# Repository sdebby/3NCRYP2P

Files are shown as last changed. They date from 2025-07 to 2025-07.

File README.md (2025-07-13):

# LoRaOmniScreenKB

Project start date: Jan. 2024

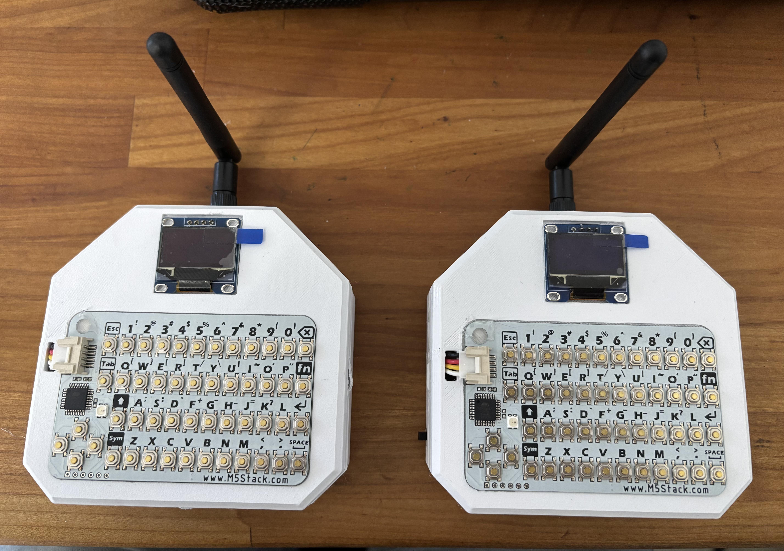
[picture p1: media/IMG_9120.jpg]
Overview picture


## Overview

3NCRYPT2P (Encrypt P2P) project, designed to enable secure, wireless communication between two devices or more, on long ranges, using LoRa (Long Range communication) technology (on 433 Mhz transmission), without cellular networks. The system features an OLED screen (SSD1306) and a CardKB keyboard for user interaction. Both sender and receiver run the same firmware, supporting encrypted messaging, key exchange, and visual feedback.

## MRD (Marketing Requirement)

- Provide a simple, secure, and portable LoRa-based communication terminal.
- Support up to 6 lines of message history on a compact OLED display.
- Enable secure key exchange and encrypted messaging between devices.
- Allow easy user input via a compact keyboard.
- Feedback for system status and errors using debug.
- New transmission protocol for secure communication between devices.

## Skill Set

- Embedded C++ programming (Arduino/ESP32).
- LoRa wireless communication.
- Cryptography (AES, SHA224, CTR mode).
- 3D design.
- 3D printing.

## Setup (Software Setup)

1. **Hardware Requirements:**
   - ESP32-S3 or ESP32-C6 development board
   - LoRa module (433MHz)
   - SSD1306 OLED display (I2C)
   - CardKB keyboard (I2C)
   - Required wiring and power supply

2. **Software Requirements:**
   - Arduino IDE (latest version recommended)
   - ESP32 board support installed via Board Manager
   - Required libraries:
     - Adafruit_SSD1306
     - LoRa
     - AES, CTR, SHA224 (Crypto libraries)
     - Preferences (for ESP32 NVS)
     - base64

3. **Flashing the Firmware:**
   - Clone or download this repository.
   - Open `LoRaOmniScreenKB.ino` in Arduino IDE.
   - Select the correct board and port.
   - Install all required libraries via Library Manager.
   - Compile and upload the firmware to your ESP32 board.

## BOM (Bill Of Materials):

**For R&D:**

1. ESP32 C6 dev kit
2. [LoRa RA02](https://docs.ai-thinker.com/_media/lora/docs/c048ps01a1_ra-02_product_specification_v1.1.pdf) (433 MHz module)
3. [SSD1306 OLED](https://www.adafruit.com/product/938) (64x64 pixels, I2C)
4. [CardKB keyboard](https://docs.m5stack.com/en/unit/cardkb_1.1) (I2C)
5. Breadboard and jumper wires
   
**For production:**
1. ESP32 C6 dev kit
2. [LoRa RA02](https://docs.ai-thinker.com/_media/lora/docs/c048ps01a1_ra-02_product_specification_v1.1.pdf) (433 MHz module)
3. [SSD1306 OLED](https://www.adafruit.com/product/938) (64x64 pixels, I2C)
4. [CardKB keyboard](https://docs.m5stack.com/en/unit/cardkb_1.1) (I2C)
5. [Charger panel](https://www.aliexpress.com/item/1005005037876729.html?spm=a2g0o.order_list.order_list_main.386.6b881802CcDzO8)
6. 433 MHz antenna.
7. LiPo battery 850 mAh.
8. On/Off switch.
9. Custom PCB manufacturing.
10. 3D printing for enclosure.

## Software:

1. Arduino IDE for coding and uploading to ESP32 C6 board.
2. KiCad for PCB design.
3. Fusion360 for 3D enclosure design

## TSD (Technical Specification)

- Microcontroller: ESP32-S3 or ESP32-C6
- Display: SSD1306 OLED, 64x64 pixel
- Keyboard: CardKB
- LoRa: 433MHz, configurable sync word, bandwidth, spreading factor, and power
- Encryption: AES-128 in CTR mode, SHA224 for message hashing, base64 for hash encoding
- Key Exchange: Random key and IV generation, secure transmission
- Error Handling: Device lockout after repeated errors, visual and serial feedback
- Message Handling: Up to 6 lines of message history, scrolling, and input editing

## Scheme

1. **Startup:**
- Display logo and initialize peripherals.
- Check for device lock status.

1. **Key Exchange:**
- On first message, generate and exchange encryption keys and IVs.
- encrypt key using predefined embedded key.
- from now on all messages will be encrypted with the exchanged key, and random IV.

1. **Message Transmission:**
- User inputs message via CardKB or serial (debug mode).
- Message is hashed, encrypted, and transmitted over LoRa.
- Await acknowledgment from receiver.

1. **Message Reception:**
- Decrypt incoming messages using the exchanged key and received IV.
- Verify hash for integrity.
- Display message on OLED and send acknowledgment.

1. **Error Handling:**
- If hash check fails or no acknowledgment is received, display message on OLED, handle retries, and lock device after 10 repeated errors.

### Transmission Protocol
| Field | Description |
|---|---|
| Setup bit | indicator for message type |
| Payload | Encrypted message content |

**Case Setup Bit = 0:**
Packet format:
A | B | C | D | E 

A - Setup bit (Byte) (0).

B - Key length (byte).

C - Key (byte array).

D - IV length(byte).

E - IV (byte array)

**Case Setup Bit = 1:**
Packet format:

A | B | C | D | E | F | G

A - Setup bit (byte) (1).

B - IV length (byte).

C - IV (byte array).

D - payload length (byte).

E - payload (byte array).

F - Hash length (byte).

G - Hash - Base64 (SHA224(payload)) (byte array)

**Case Setup Bit = 2:**
Packet format:

A | B

A - Setup bit (byte) (2).

B - payload reply (int).

### Reply payload
* 200 if payload hash OK

* 502 if payload hash not OK

### Transmission scheme example

Case setup bit = 0

  generate random key
  generate random iv
  Send message by this order:
    Setup
      - 0 for key replace.
    key size
    key
    iv size
    iv

Case setup bit = 1
  User payload input
  Encrypt payload using key and IV
  Create SHA224 hash of payload
  Convert hash to Base64
  Send message by this order:
    Setup
      - 1 for normal text payload
    payload size 
    payload 
    iv size 
    iv 
    text hash size 
    text hash

  Getting random IV

Listen to receiver hash result.
print result status (OK/wrong hash)

if result is wrong hash -> procedure to setup bit 0 case, count number of wrong hashes, if more than 10 times, lock device.

## Receiving payload
Receive message by this order:
  Setup
    - 0 for encrypted new key
    - 1 for normal text payload
    - 2 payload reply
  payload size 
  payload 
  iv size 
  iv 
  text hash size 
  text hash

Decrypt message using key and IV from message
Create SHA224 hash of message
Compare received hash and created hash.

reply on compare results.

Case setup bit = 2
  Sending payload reply (OK/ERROR)

## Security features

1. **Encryption:** All messages are encrypted using AES-128 in CTR mode.
2. **Key Exchange:** Secure key exchange is performed during the initial connection.
3. **Integrity Check:** Message integrity is verified using SHA224 hashes.
4. **Brute Force Protection:** After 10 consecutive errors, the device locks out to prevent further communication until reset.

## Schematics

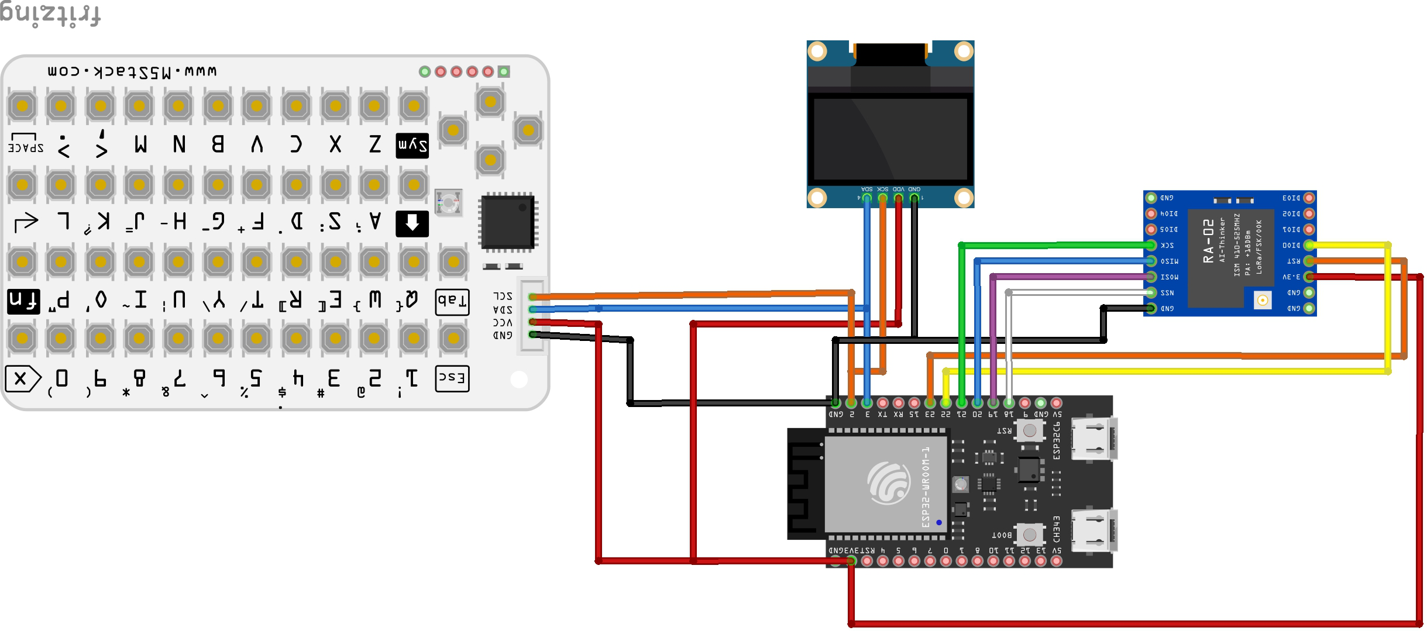
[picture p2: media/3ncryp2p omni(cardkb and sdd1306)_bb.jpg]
Scheme


## PCB

* PCB design using KiCad
* 2 layers PCB
* PCB manufacturing using PCBWay
  
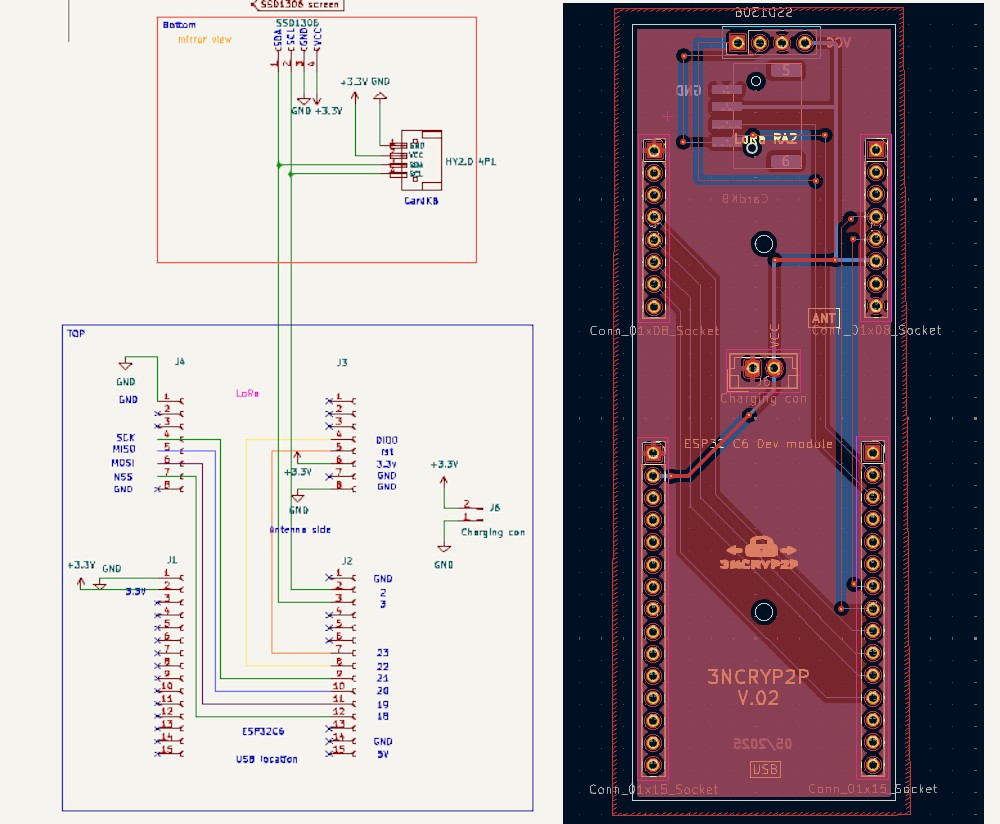
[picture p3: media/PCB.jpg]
PCB


## Hardware assembly:

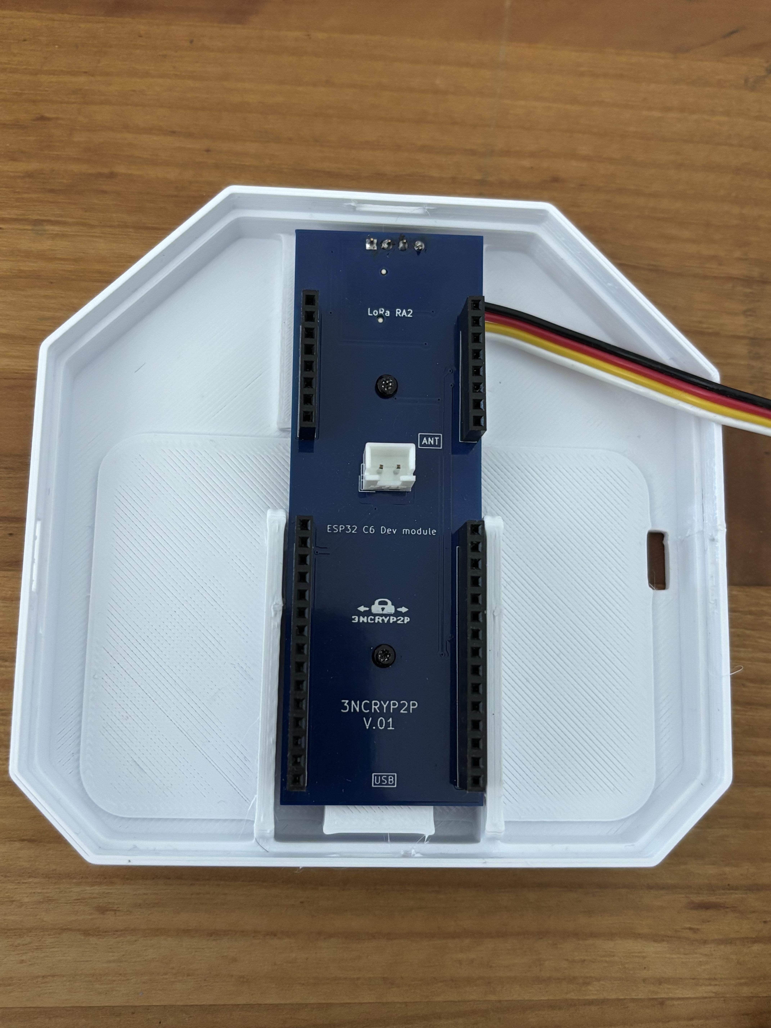
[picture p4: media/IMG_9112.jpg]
PCB Assembly on 3D print top enclosure


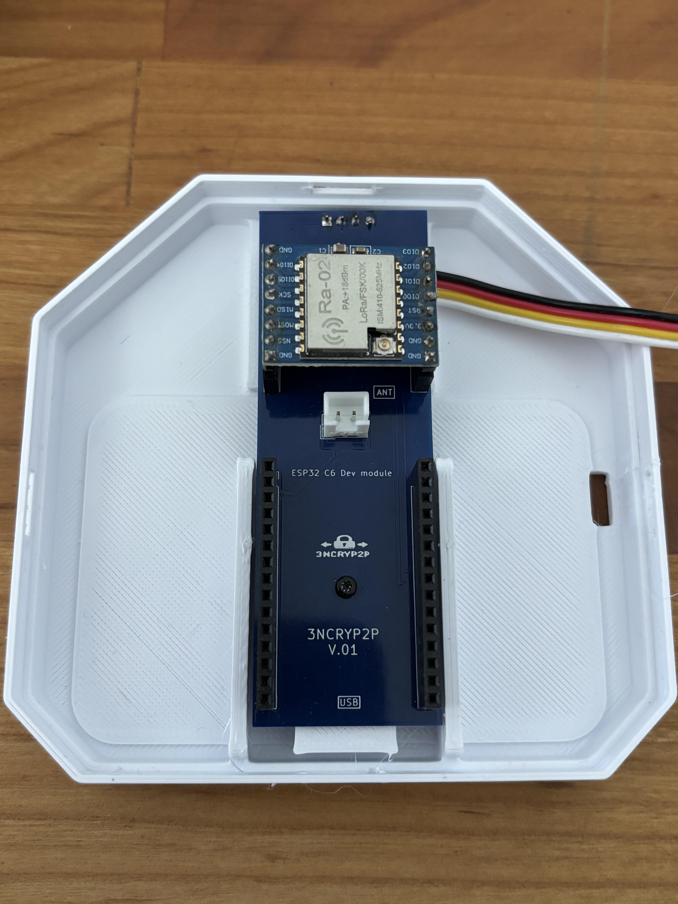
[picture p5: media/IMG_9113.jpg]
Adding RA02 LoRa module


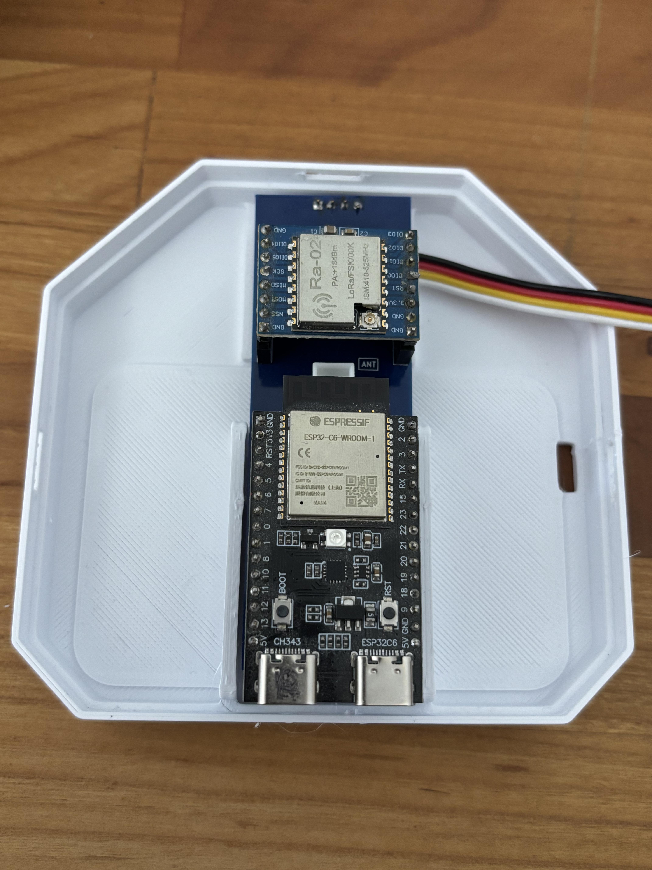
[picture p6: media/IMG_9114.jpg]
Adding ESP32C6


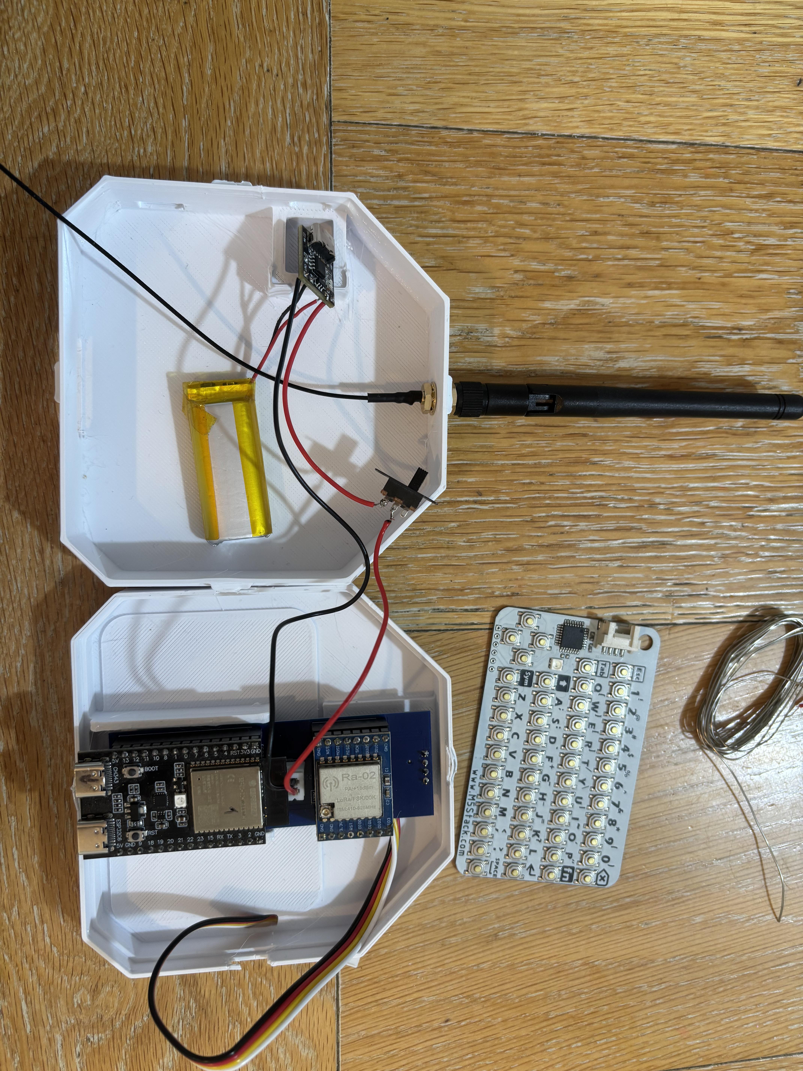
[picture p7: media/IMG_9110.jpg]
Adding USB charging, Antenna and battery


### 3D enclosure design

* Using Fusion360
* 3D print using Ender 5 plus with PLA filament.
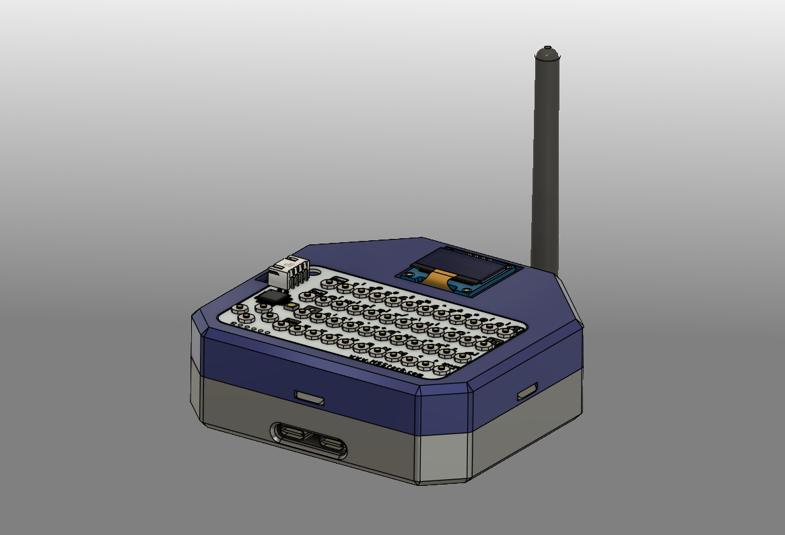
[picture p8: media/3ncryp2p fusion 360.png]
Fusion360 Design


## Range test
Sender

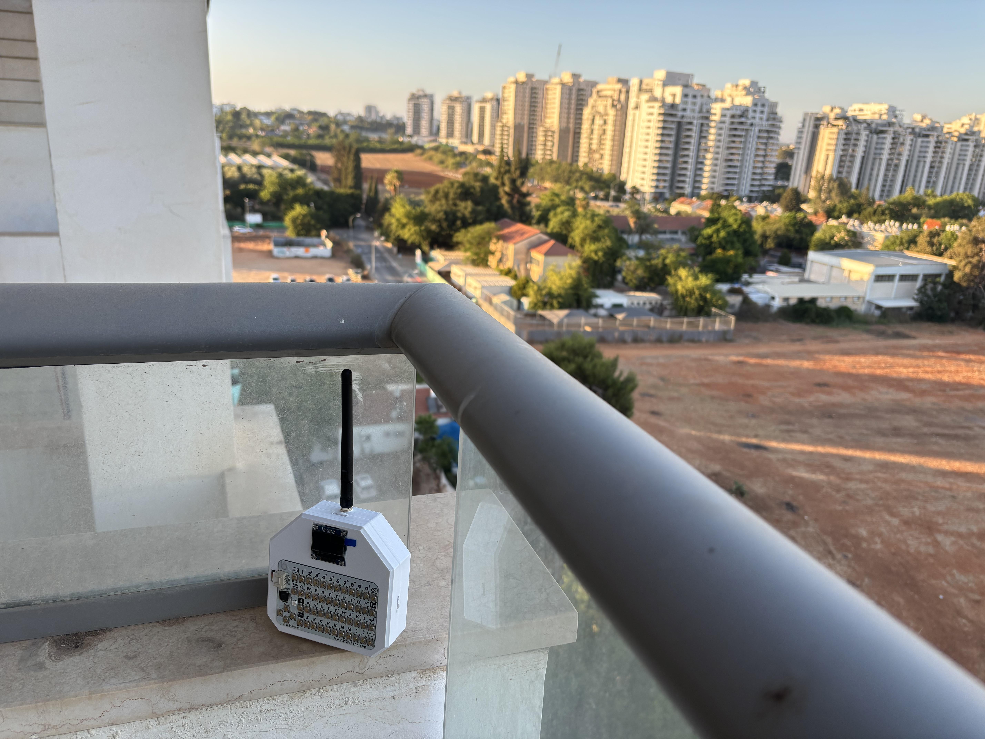
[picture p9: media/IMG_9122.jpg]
Sender


Receiver

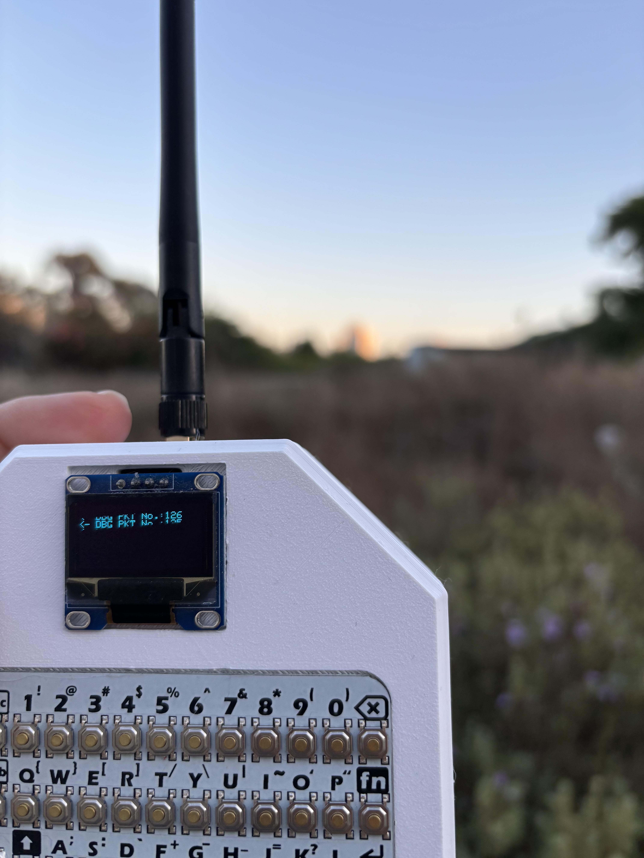
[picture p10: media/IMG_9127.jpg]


**Line of sight distance** 1.5 km

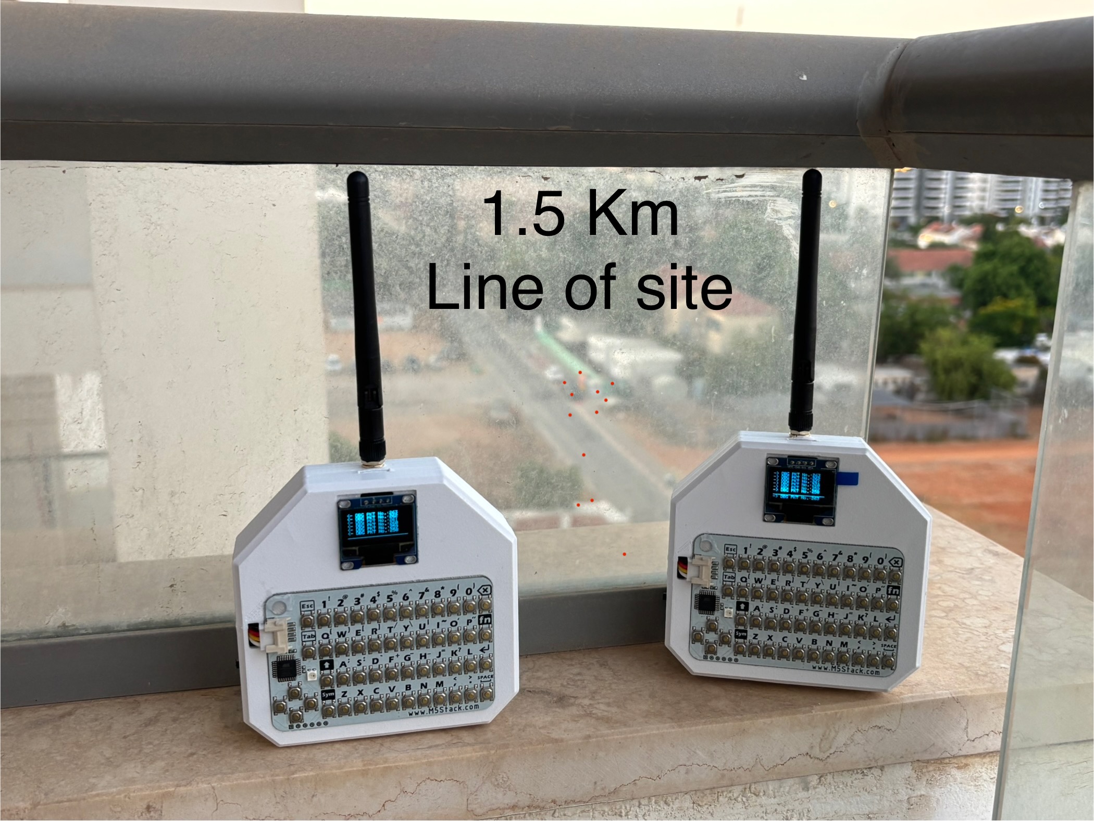
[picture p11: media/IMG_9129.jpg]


**Non-line of sight distance** 400 - 500 m

## Video

(https://youtu.be/woUXP3gD4LY)

## TODO
- [ ] Implement a short range, predefined key exchange mechanism, using Thread protocol or ESP-NOW.
- [ ] Implement a more robust error handling mechanism.
- [ ] Add support for multiple devices in a network.
- [ ] Replace screen with a larger one for better user experience.
- [ ] Implement a more user-friendly interface for message input and display - replace screen with 128x64 OLED display or E-INK display.
- [ ] Implement a secure bootloader to prevent unauthorized firmware updates. 
- [ ] Implement user message history storage and retrieval.

## Achilles heel
The Achilles' heel of the project is the hardcoded key embedded in the code. This key is used to encrypt the initial key exchange, which is crucial for secure communication. If an attacker gains access to the source code, they can extract this key and compromise the security of the entire system. 
To mitigate this risk, it is essential to implement a secure key exchange mechanism that does not rely on a hardcoded key. This could involve using public key cryptography or a secure key exchange protocol like Diffie-Hellman.

A predefined key exchange mechanism, such as using Thread protocol or ESP-NOW, could be implemented to securely exchange keys between devices without relying on a hardcoded key. This would enhance the security of the system and protect against potential attacks.

Another approach can be sending only half of the key over the air and displaying the other half on the screen, allowing the user to manually input it into the other device. This would require user interaction but would eliminate the need for a hardcoded key in the code.

Then the new, predefined key will be stored in the device's non-volatile storage (NVS) for future use, ensuring that the key is not hardcoded in the firmware.

## Feedback

If you have any feedback, please reach out to us at mailto:shmulik.debby@gmail.com

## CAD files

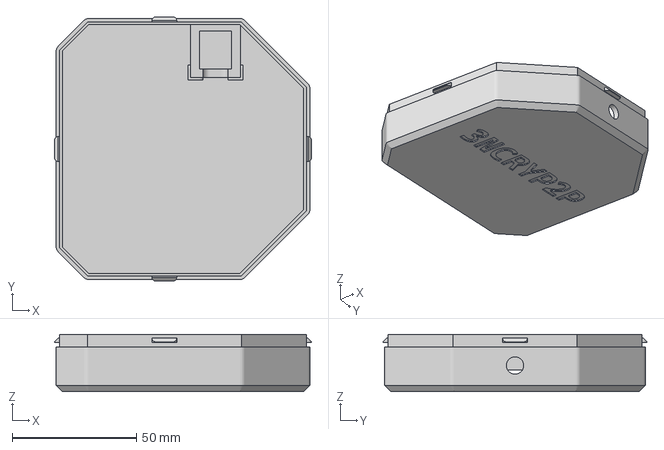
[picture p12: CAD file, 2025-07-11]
3D/3ncryp2p Enclosure BOTTOM.3mf
103.4 x 106.3 x 23.0 mm

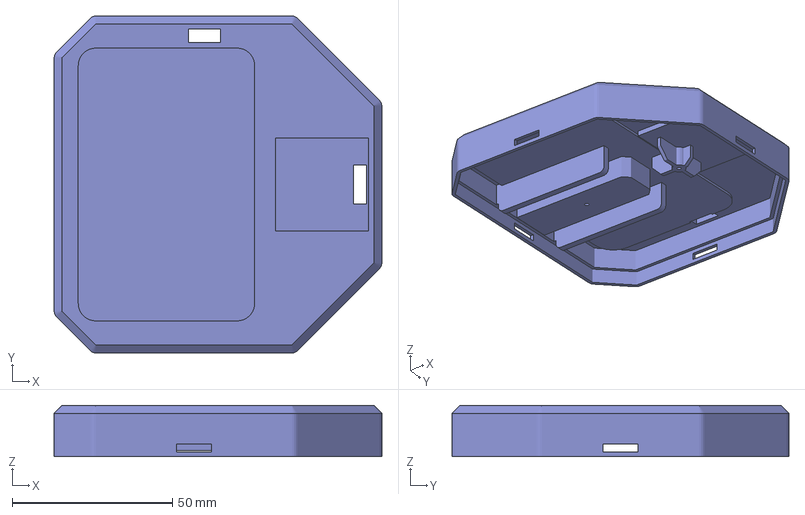
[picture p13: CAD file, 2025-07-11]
3D/3ncryp2p Enclosure TOP.3mf
102.1 x 105.0 x 16.0 mm

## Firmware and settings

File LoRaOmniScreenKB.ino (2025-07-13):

/*
11.04.2025
3NCRYPT2P project
__ Omni Screen and keyboard program __

This code will be implemented in both devices (Sender and Receiver)
the communication will be thru screen(SSD1306) and keyboard (CardKB).
** Change the AIM flag to generate automated interval messages
** Chenge to core debug level (in arduino IDE menu - Tools) to communicate using console and see system messages
*/  

#include <SPI.h>
#include <LoRa.h>
#include <AES.h>
#include "base64.hpp"
#include <base64.h>
#include <CTR.h>
#include <SHA224.h>
#include <Preferences.h>
#include "esp32-hal-log.h"

// Define screen and keyboard
#include <Wire.h>
#include <Adafruit_SSD1306.h>

#define CARDKB_ADDR 0x5F 
#define SCRN_ADDR 0x3C 

// Define screen width and height
#define SCREEN_WIDTH 128
#define SCREEN_HEIGHT 64
#define MAX_LINES 6  // Maximum number of lines that can fit on screen
#define LINE_HEIGHT 8  // Height of each line in pixels

Adafruit_SSD1306 display(SCREEN_WIDTH, SCREEN_HEIGHT, &Wire, -1);
int TextSize = 1;
String lines[MAX_LINES];  // Array to store lines
int currentLine = 0;      // Current line position

#if CONFIG_IDF_TARGET_ESP32S3  // Define LoRa-ESP32 pin out for ESP32 - S3
  #define BoadMSG  "[*] ESP32-S3 board found"
  #include <WiFi.h>
  #define ss 10
  #define rst 6
  #define dio0 5

#elif CONFIG_IDF_TARGET_ESP32C6  // Define LoRa-ESP32 pin out for ESP32 - C6
  #define BoadMSG  "[*] ESP32-C6 board found"
  #include <WiFi.h>
  #define ss 18
  #define rst 23
  #define dio0 22
  #define WireSDA 3
  #define WireSCL 2

  #else
  #error "[X] This code is for ESP32 S3 and ESP32 C6 only."
#endif

bool Consl = false; // Console mode
bool TransmissionACK = true; // Transmission acknowledge by 2nd device flag
unsigned long TransmissionMillis = 0;
const long TransmissionRcvACKInterval = 3.5 * 1000; // waiting time for Tramsnission acknowledge (milliseconds)

  // Define Encryption key
byte keyOriginal[16] = {0x5E, 0xC3, 0x7A, 0x1F, 0xB8, 0x9D, 0x42, 0x86, 0xE4, 0x3B, 0x60, 0xF5, 0x2C, 0xAB, 0x91, 0x08};
byte key[16] ;
byte iv[16] ;
CTR<AES128> ctr;

  // Debug - send messages in intervals
bool AIM = true; // AIM = Automated Interval Messages
  int counter = 0;
  unsigned long previousMillis = 0; 
  const long interval = 10 * 1000;  // intervals to send messages in ms


String RecievedMSG_Pack = "";
int RTN_OK = 200;
int RTN_NG = 502;

bool FirstMsg = true; // Check if this is the first message
int ErrCount = 0;
int ErrAllowed = 10;
Preferences preferences;
String PayloadInput = "";
String ReSendPayloadInput = "";

void setup() {
  Serial.begin(115200);
  while (!Serial);
  Serial.println("**-- LoRa OMNI SC-KB --**");
  // Get compiled debug level
  #ifdef CORE_DEBUG_LEVEL
    Serial.print("[*] CORE_DEBUG_LEVEL Value: ");
    Serial.println(CORE_DEBUG_LEVEL);  // Try printing its value
    #if CORE_DEBUG_LEVEL == 4// if compiled debug level = DEBUG
       Consl = true; 
    #endif
  #else
    Serial.println("[*] CORE_DEBUG_LEVEL is NOT defined.");
  #endif

  // I2C pins
  Wire.begin(WireSDA, WireSCL);
  // Initialize the display
  if (!display.begin(SSD1306_SWITCHCAPVCC, SCRN_ADDR)) {
    Serial.println(F("[X] SSD1306 allocation failed"));
    for (;;);
  }
  // initize display SSD1306
  LogDisp(); // Display logo on screen
  intDisp();
  intPref();
  if (preferences.getBool("DeviceLOCK",false)){ //TODO - set red light
    LockLoop();
  }
  Serial.println(BoadMSG);
	// Initialize LoRa 
  LoRa.setPins(ss, rst, dio0);
  if (!LoRa.begin(433E6)) {
    log_d("[X] Starting LoRa failed!");
    delay(100);
    while (1);
  }
  SetLoRaParam();// LoRa parameters
}

void loop() {
  unsigned long currentMillis = millis();
  onReceive(LoRa.parsePacket());
  delay(50);
  if (Consl && Serial.available()) { // Get text from serial if using debug 
    PayloadInput = Serial.readStringUntil('\n');
    SndCmd(PayloadInput);
  } else { // Get text from CardKB
    Wire.requestFrom(CARDKB_ADDR, 1);  
    while (Wire.available())  {
      char c = Wire.read();  // Store the received data.  
      PayloadInput += String(c) ;
      if (c != 0) {
        if (c == 13){  // Enter
          PayloadInput.remove (PayloadInput.length() - 1); // remove last charecter
          SndCmd(PayloadInput);
          String TmpPayloadInput = PayloadInput;
          ReSendPayloadInput = PayloadInput; // for resending payload if needed
          PayloadInput = "-> " + TmpPayloadInput;
          scrollLines();
          PayloadInput = "";
          redrawDisplay();
        }
        else if (c == 8) {  // Backspace
          int cursorX = display.getCursorX() - 6 * TextSize;
          int cursorY = display.getCursorY();
          if (cursorX < 0) cursorX = 0 ;
          display.setCursor(cursorX, cursorY);
          display.fillRect(cursorX,cursorY,cursorX + 6 * TextSize , cursorY + LINE_HEIGHT * TextSize,BLACK);
          display.display();
          if (PayloadInput.length() > 0) {
            PayloadInput.remove (PayloadInput.length() - 2); // remove last charecter
          }
          c = 0;
        } else {
        display.print(c);
        }
        display.display();
      }
    }
  }
  if (AIM){ // Generate message and send
    if (currentMillis - previousMillis >= interval) {
      previousMillis = currentMillis;
      Serial.print("[*] Sending DEBUG packet: ");
      Serial.println(counter);
      String Ttext = "DBG PKT No.:" + String(counter);
      PayloadInput = "-> " + Ttext;
      scrollLines();
      redrawDisplay();
      SndCmd(Ttext);
      counter ++;
      }
  }
  // Check if received acknowledge
  if ( currentMillis >= TransmissionMillis && currentMillis - TransmissionMillis >= TransmissionRcvACKInterval && !TransmissionACK) {
    // Message acknowledge did not receaved after TransmissionACKInterval time
    Serial.print("[X] Error sending message - no ACK");
    TransmissionACK = true;
    PayloadInput = "-X Err sending msg";
    scrollLines();
    PayloadInput = "";
    redrawDisplay();
  }

}

/* --------------------------------------- */

  // Shift all lines down by one
void scrollLines() {
  for (int i = MAX_LINES - 1; i > 0; i--) {
    lines[i] = lines[i - 1];
  }
  // Add new line at the top
  lines[0] = PayloadInput;
}

  // draw display again 
void redrawDisplay() {
  display.clearDisplay();
  for (int i = 0; i < MAX_LINES; i++) {
    display.setCursor(0, i * LINE_HEIGHT);
    display.print(lines[i]);
  }
  
  // Draw input line and separator
  display.setCursor(0, SCREEN_HEIGHT - LINE_HEIGHT);
  display.print(PayloadInput);
  int BottomLineY = SCREEN_HEIGHT - LINE_HEIGHT - 2;
  display.drawFastHLine(0, BottomLineY, SCREEN_WIDTH, WHITE);
  display.display();
}

  //initialize preferences
void intPref(){
  preferences.begin("3NCRYPT2P", false); // The second parameter is false for read/write access. Use true for read-only.
  if (AIM){
    preferences.clear();
  }
}

  // Send payload
void SndCmd(String Ttext){  // prepare and send message
  if (FirstMsg){
      NewKey();
      delay(1500);
      FirstMsg = false;
  }
  NewIV();  // generate random IV
    // Hashing text and converting to byte
  String TxtHash = Hash_base64(Ttext.c_str());
  byte* TxtSHA224 = stringToByteArray(TxtHash);
    // Encrypting
  byte* plaintext = stringToByteArray(Ttext);
  SetEnc(key,sizeof(key));
  byte ciphertext[Ttext.length()]; // Buffer for the ciphertext
  ctr.encrypt(ciphertext, plaintext, Ttext.length());
  log_d("[*] Before Encryption: %s",Ttext);
    // send packet
  SendMSG(1, Ttext.length() , ciphertext , sizeof(iv), iv, TxtHash.length(), TxtSHA224);
}

// Generate a new key , encrypt with predefine key and random IV and send
void NewKey(){
  log_d("[*] Creating new key --");
  for (int i =0 ; i<sizeof(keyOriginal) ; i++){
    key[i] = RandByte();
  }
  NewIV();
  SetEnc(keyOriginal,sizeof(keyOriginal));
  byte ciphertext[sizeof(key)]; // Buffer for the ciphertext
  ctr.encrypt(ciphertext, key, sizeof(key));

    // Send message with Setup 0
  SendMSG(0, sizeof(ciphertext),ciphertext, sizeof(iv), iv, 0, 0);
}

  // Set encryption parameters
void SetEnc(byte* inputkey,int KeySize){
  if (!ctr.setKey(inputkey, KeySize))
    log_d("[X] setKey failes!");
  if (!ctr.setIV(iv, sizeof(iv))) 
    log_d("[X] setIV failes!");
}

  // Setting LoRa parameters
void SetLoRaParam(){
  LoRa.setSyncWord(0xB2);  //Unique Sync Word
  LoRa.setSignalBandwidth(41.7E3); //7.8E3, 10.4E3, 15.6E3, 20.8E3, 31.25E3, 41.7E3, 62.5E3, 125E3, and 250E3.
  LoRa.setSpreadingFactor(9) ;  // Supported values are between `6` and `12`. If a spreading factor of `6` is set, implicit header mode must be used to transmit and receive packets.
  LoRa.setTxPower(17); //2-17 
  LoRa.enableCrc();  
  log_d("[V] LoRa init succeeded.");
}

  // generate new IV
void NewIV(){
  for (int i =0 ; i<sizeof(iv) ; i++){
    iv[i] = RandByte();
  }
}

  // onReceive  function
void onReceive(int packetSize){
  if (!packetSize) return; //Drop packet
      // Print packet data
      FirstMsg = false;
      Serial.print("[*] Packet size: "); //print to serial
      Serial.print(packetSize);
      String MyText = "  SNR: ";
      MyText += LoRa.packetSnr();
      MyText += "  Signal: ";
      float RSSI_pre = (1.0 - (-1*LoRa.packetRssi())/125.0) * 100.0 ;
      MyText += RSSI_pre;
      MyText += " %";

      Serial.println(MyText);
      RecievedMSG_Pack += "[*] Packet received - "; //print to portal
      RecievedMSG_Pack += MyText;
         /* read packet */

    // read setup param
  int SetupParam = LoRa.read();
  switch (SetupParam) {
    case 0:{//Update new key
        // Read encrypted key
      int KeySize = LoRa.read();
      byte EncKey[KeySize];
      for (int i = 0; i < KeySize; i++) {
        EncKey[i] = LoRa.read();
        }

          // Read iv
      int IV64Size = LoRa.read();
      for (int i = 0; i < IV64Size; i++) {
        iv[i] = LoRa.read();
      }
          log_d("New key received,Key size: %d  IV size: %d",KeySize,IV64Size);
          RecievedMSG_Pack += "[*] New key received";
      SetEnc(keyOriginal,16);
      ctr.decrypt(key, EncKey, KeySize);
      for(int i=0;i<sizeof(key);i++){
        Serial.print(String(key[i], HEX));
        Serial.print(" ");
      }
      Serial.println();    
    break; }

    case 1:{ // continue read packet
          // Read payload
      byte payloadSize = LoRa.read();
      byte payload[payloadSize];
      for (int i = 0; i < payloadSize; i++) {
        payload[i] = LoRa.read();
      }

        // Read iv
      byte IV64Size = LoRa.read();
      for (int i = 0; i < IV64Size; i++) {
        iv[i] = LoRa.read();
      }

        //Read text hash
      byte TxtHashSize = LoRa.read();
      String TxtHashStr;
        for (int i = 0; i < TxtHashSize; i++) {
          TxtHashStr +=(char)LoRa.read();
      }
        // Decrypt
      SetEnc(key,16);
      byte decryptedtext[payloadSize]; // Buffer for the decrypted text
      ctr.decrypt(decryptedtext, payload, payloadSize);
      Serial.print("[*] Received packet: ");
      String Ttext;
      for (int i=0 ; i<sizeof(decryptedtext) ; i++){
        Ttext += char(decryptedtext[i]);
      }
      Serial.println(Ttext);
        // Check hash
      if (CompareHash(Ttext, TxtHashStr)){
        RecievedMSG_Pack += "[V] " + Ttext ;
        String receivedMessage = "<- " + Ttext;  // Add prefix for received message
        scrollLines();
        lines[0] = receivedMessage;  // Store the received message
        redrawDisplay();
        SendMSG(2, RTN_OK ,0 ,0 , 0 , 0 , 0);
      } else {
        RecievedMSG_Pack += "[X] Error message hash";
        SendMSG(2, RTN_NG ,0 ,0 , 0 , 0 , 0);
      } 
  break;}

  case 2:{  //payload reply
    int PKT;
    PKT = LoRa.read();
    if (PKT == RTN_OK){
      ErrCount = 0;
      log_d("[V] Packet recieved OK");
      TransmissionACK = true; 
      // LockLoop(); //Debug
    } else { // Packet acknowledge receive error
        ErrCount += 1;
        if (ErrCount == ErrAllowed){ // large errors can indicate keybrote force - system will lock
          LockLoop();
          log_d("[X] Device Locked - Resync master key");
        } else {
          log_d("[X] Wrong Hash on receiver, lockup in %d  attempts.",ErrAllowed - ErrCount);
          NewKey();
          log_d("[*] Sending payload again");
          delay(500);
          SndCmd(ReSendPayloadInput);
        }
      }
  break;}

  default:{
      // do something else
  break;}
  }
}

  // This is a lock loop, it will lock unit for to many errors
void LockLoop(){
  preferences.putBool("DeviceLOCK",true);
  preferences.end();
  Serial.println ("To many errors - unit will lock !\nResync keys to enable unit transmission");
  while (true){
    Serial.print(" .");
    delay(1000);
  }
}

  /* send message via LoRa
  Input:
  Setup (0) - SEND NEW KEY
  Key size (int)
  Encrypted key (byte array)
  IV size (int)
  IV (byte array)
  ---
  Setup (1) - SEND PAYLOAD
  payload size (int)
  payload (byte array)
  IV size (int)
  IV (byte array)
  text hash size (int)
  text hash (byte array)
  ---
  Setup (2) - PAYLOAD REPLY
  Payload reply (int)
  */
  // send payload via LoRa
void SendMSG(int Setup,int payloadSize, byte* payload, int IVSize, byte* IV ,int TxtHashSize, byte* TxtHash){
  LoRa.beginPacket();
    LoRa.write(Setup);
    LoRa.write(payloadSize);
  if (Setup != 2){ // End of sending payload reply
    LoRa.write(payload,payloadSize);
    LoRa.write(IVSize);
    LoRa.write(IV,IVSize);
    LoRa.write(TxtHashSize);
    LoRa.write(TxtHash,TxtHashSize);

    TransmissionACK = false; 
    TransmissionMillis = millis();
  }
  LoRa.endPacket();
}

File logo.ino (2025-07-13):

// 3ECRYP2P logo display on SSD1306 screen
const unsigned char logo_bitmap[] = {
0x00, 0x00, 0x00, 0x00, 0x00, 0x00, 0x00, 0x00, 0x00, 0x00, 0x00, 0x00, 0x00, 0x00, 0x00, 0x00,
0x00, 0x00, 0x00, 0x00, 0x00, 0x00, 0x00, 0x00, 0x00, 0x00, 0x00, 0x00, 0x00, 0x00, 0x00, 0x00,
0x00, 0x00, 0x00, 0x00, 0x00, 0x00, 0x00, 0x00, 0x00, 0x00, 0x00, 0x00, 0x00, 0x00, 0x00, 0x00,
0x00, 0x00, 0x00, 0x00, 0x00, 0x00, 0x00, 0x00, 0x00, 0x00, 0x00, 0x00, 0x00, 0x00, 0x00, 0x00,
0x00, 0x00, 0x00, 0x00, 0x00, 0x00, 0x00, 0x00, 0x00, 0x00, 0x00, 0x00, 0x00, 0x00, 0x00, 0x00,
0x00, 0x00, 0x00, 0x00, 0x00, 0x00, 0x00, 0x3F, 0xFC, 0x00, 0x00, 0x00, 0x00, 0x00, 0x00, 0x00,
0x00, 0x00, 0x00, 0x00, 0x00, 0x00, 0x01, 0xFF, 0xFF, 0x80, 0x00, 0x00, 0x00, 0x00, 0x00, 0x00,
0x00, 0x00, 0x00, 0x00, 0x00, 0x00, 0x07, 0xFF, 0xFF, 0xE0, 0x00, 0x00, 0x00, 0x00, 0x00, 0x00,
0x00, 0x00, 0x00, 0x00, 0x00, 0x00, 0x1F, 0xFF, 0xFF, 0xF8, 0x00, 0x00, 0x00, 0x00, 0x00, 0x00,
0x00, 0x00, 0x00, 0x00, 0x00, 0x00, 0x3F, 0xE0, 0x07, 0xFC, 0x00, 0x00, 0x00, 0x00, 0x00, 0x00,
0x00, 0x00, 0x00, 0x00, 0x00, 0x00, 0x7F, 0x00, 0x00, 0xFE, 0x00, 0x00, 0x00, 0x00, 0x00, 0x00,
0x00, 0x00, 0x00, 0x00, 0x00, 0x00, 0xFE, 0x00, 0x00, 0x7F, 0x00, 0x00, 0x00, 0x00, 0x00, 0x00,
0x00, 0x00, 0x00, 0x00, 0x00, 0x00, 0xFE, 0x00, 0x00, 0x7F, 0x00, 0x00, 0x00, 0x00, 0x00, 0x00,
0x00, 0x00, 0x00, 0x00, 0x00, 0x01, 0xFE, 0x00, 0x00, 0x7F, 0x00, 0x00, 0x00, 0x00, 0x00, 0x00,
0x00, 0x00, 0x00, 0x00, 0x00, 0x01, 0xFE, 0x00, 0x00, 0x7F, 0x00, 0x00, 0x00, 0x00, 0x00, 0x00,
0x00, 0x00, 0x00, 0x00, 0x00, 0x01, 0xFE, 0x00, 0x00, 0x7F, 0x00, 0x00, 0x00, 0x00, 0x00, 0x00,
0x00, 0x00, 0x00, 0x00, 0x00, 0x00, 0xFE, 0x00, 0x00, 0x7F, 0x00, 0x00, 0x00, 0x00, 0x00, 0x00,
0x00, 0x00, 0x00, 0x00, 0x00, 0x00, 0xFE, 0x00, 0x00, 0x7F, 0x00, 0x00, 0x00, 0x00, 0x00, 0x00,
0x00, 0x00, 0x00, 0x00, 0x00, 0x0F, 0xFF, 0xFF, 0xFF, 0xFF, 0xF0, 0x00, 0x00, 0x00, 0x00, 0x00,
0x00, 0x00, 0x00, 0x00, 0x00, 0x3F, 0xFF, 0xFF, 0xFF, 0xFF, 0xFC, 0x00, 0x00, 0x00, 0x00, 0x00,
0x00, 0x00, 0x00, 0xC0, 0x00, 0x7F, 0xFF, 0xFF, 0xFF, 0xFF, 0xFE, 0x00, 0x03, 0x00, 0x00, 0x00,
0x00, 0x00, 0x03, 0xC0, 0x00, 0x7F, 0xFF, 0xFF, 0xFF, 0xFF, 0xFE, 0x00, 0x03, 0xC0, 0x00, 0x00,
0x00, 0x00, 0x0F, 0xC0, 0x00, 0x7F, 0xFF, 0xFF, 0xFF, 0xFF, 0xFE, 0x00, 0x03, 0xF0, 0x00, 0x00,
0x00, 0x00, 0x3F, 0xFF, 0xC0, 0x7F, 0xFF, 0xF0, 0x0F, 0xFF, 0xFE, 0x03, 0xFF, 0xFC, 0x00, 0x00,
0x00, 0x00, 0xFF, 0xFF, 0xF0, 0x7F, 0xFF, 0xF0, 0x0F, 0xFF, 0xFE, 0x1F, 0xFF, 0xFF, 0x00, 0x00,
0x00, 0x03, 0xFF, 0xFF, 0xF8, 0x7F, 0xFF, 0xF0, 0x0F, 0xFF, 0xFE, 0x1F, 0xFF, 0xFF, 0xC0, 0x00,
0x00, 0x07, 0xFF, 0xFF, 0xF8, 0x7F, 0xFF, 0xF8, 0x1F, 0xFF, 0xFE, 0x1F, 0xFF, 0xFF, 0xC0, 0x00,
0x00, 0x01, 0xFF, 0xFF, 0xF0, 0x7F, 0xFF, 0xFC, 0x3F, 0xFF, 0xFE, 0x0F, 0xFF, 0xFF, 0x00, 0x00,
0x00, 0x00, 0x3F, 0xFF, 0xE0, 0x7F, 0xFF, 0xFC, 0x3F, 0xFF, 0xFE, 0x0F, 0xFF, 0xFE, 0x00, 0x00,
0x00, 0x00, 0x0F, 0xC0, 0x00, 0x7F, 0xFF, 0xFC, 0x3F, 0xFF, 0xFE, 0x00, 0x03, 0xF0, 0x00, 0x00,
0x00, 0x00, 0x03, 0xC0, 0x00, 0x7F, 0xFF, 0xFF, 0xFF, 0xFF, 0xFE, 0x00, 0x03, 0xE0, 0x00, 0x00,
0x00, 0x00, 0x00, 0x80, 0x00, 0x7F, 0xFF, 0xFF, 0xFF, 0xFF, 0xFE, 0x00, 0x01, 0x00, 0x00, 0x00,
0x00, 0x00, 0x00, 0x00, 0x00, 0x3F, 0xFF, 0xFF, 0xFF, 0xFF, 0xFC, 0x00, 0x00, 0x00, 0x00, 0x00,
0x00, 0x00, 0x00, 0x00, 0x00, 0x1F, 0xFF, 0xFF, 0xFF, 0xFF, 0xF8, 0x00, 0x00, 0x00, 0x00, 0x00,
0x00, 0x00, 0x00, 0x00, 0x00, 0x00, 0x00, 0x00, 0x00, 0x00, 0x00, 0x00, 0x00, 0x00, 0x00, 0x00,
0x00, 0x00, 0x00, 0x00, 0x00, 0x00, 0x00, 0x00, 0x00, 0x00, 0x00, 0x00, 0x00, 0x00, 0x00, 0x00,
0x00, 0x00, 0x00, 0x00, 0x00, 0x00, 0x00, 0x00, 0x00, 0x00, 0x00, 0x00, 0x00, 0x00, 0x00, 0x00,
0x00, 0x00, 0x00, 0x00, 0x00, 0x00, 0x00, 0x00, 0x00, 0x00, 0x00, 0x00, 0x00, 0x00, 0x00, 0x00,
0x00, 0x00, 0x00, 0x00, 0x00, 0x00, 0x00, 0x00, 0x00, 0x00, 0x00, 0x00, 0x00, 0x00, 0x00, 0x00,
0x00, 0x00, 0x00, 0x00, 0x00, 0x00, 0x00, 0x00, 0x00, 0x00, 0x00, 0x00, 0x00, 0x00, 0x00, 0x00,
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
};

  // Logo Display SSD1306
void LogDisp(){
  display.clearDisplay();
  display.drawBitmap(0,0,logo_bitmap, 128, 64, 1);
  display.display();
  delay(3000);
}
